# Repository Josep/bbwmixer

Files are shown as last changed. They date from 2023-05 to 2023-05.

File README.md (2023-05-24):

Audio Mixer and Volume MIDI controlled
======================================

This is a simple audio mixer with 4 analog stereo inputs and 1 output. The main volume 
and the volume of each input is controlled by MIDI messages.

The main volume is handled by the PGA2311 chip. The level of the 4 inputs are controlled by the
digital potentiometer MCP4251.

All the components are controlled by a Beaglebone White.

The midi interface is a classical one -not USB- with optocoupler 6N138.

The midi messages are handled in the PRU (Programmable Realtime Unit) of the Beaglebone.

No need to install capes or device tree overlays.

If you don't have a midi controller, the levels can be controlled from a web page too. In that case, an ethernet connection is needed.

Although the analog and digital power supply and grounds are separated in the design, they can be connected together with a jumper. So, the power from the BeagleBone will supply all the circuit. In my case, the results are good enough with the jumpers.

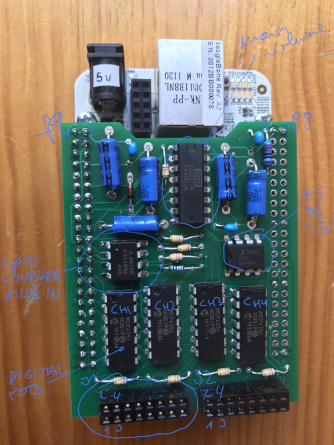
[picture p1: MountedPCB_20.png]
photo of mounted board here


J1 pinout
---------

    1  Left CH1
    2  Left CH1 GND  
    3  Right CH1
    4  Right CH1 GND
    5  Left CH2 GND
    6  Left CH2
    7  Right CH2 GND
    8  Right CH2
    9  Left CH3
    10 Left CH3 GND
    11 Right CH3
    12 Right CH3 GND
    13 Left CH4 GND
    14 Left CH4
    15 Right CH4 GND
    16 Right CH4

J2 pinout
---------

    1  Left out
    2  Left out GND
    3  Right out
    4  Right out GND
    5  Midi in (optocoupler)
    6  NC
    7  Midi in (R220)
    8  NC
    9  NC
    10 NC
    11 +3.3V
    12 NC
    13 +5V Digital
    14 +5V Analog
    15 Digital GND
    16 Analog GND

Beaglebone pins used
--------------------

    P8_1   GND
    P8_2   GND
    P9_1   GND
    P9_2   GND
    P9_4   VDD_3V3
    P9_8   +5V
    P9_11  gpio0_30  MUTE PGA2311
    P9_12  gpio1_28  ZCEN PGA2311
    P9_13  gpio0_31  CS CH3 MCP4251
    P9_14  gpio1_18  CS CH4 MCP4251
    P9_15  gpio1_16  SHDN CH1 MCP4251
    P9_16  gpio1_19  CS CH2 MCP4251
    P9_17  gpio0_5   CS PGA2311
    P9_21  gpio0_3   SPI DATA OUT PGA2311
    P9_22  gpio0_2   SPI CLK PGA2311
    P9_23  gpio1_17  SHDN CH2 MCP4251
    P9_25  gpio3_21  SHDN CH3 MCP4251
    P9_27  gpio3_19  SHDN CH4 MCP4251
    P9_28  gpio3_17  CS CH1 MCP4251
    P9_29  gpio3_15  SPI DATA OUT MCP4251
    P9_30  gpio3_16  SPI DATA IN MCP4251
    P9_31  gpio3_14  SPI CLK MCP4251
    P9_42  gpio7_7   MIDI IN

MIDI Messages Handled
---------------------

    B0 44 7F  Mute ON Main Volume
    B0 44 00  Mute OFF Main Volume
    BA 46 7F  Mute ON CH1
    BA 46 00  Mute OFF CH1
    BA 47 7F  Mute ON CH2
    BA 47 00  Mute OFF CH2
    BA 48 7F  Mute ON CH3
    BA 48 00  Mute OFF CH3
    BA 49 7F  Mute ON CH4
    BA 49 00  Mute OFF CH4
    B0 07 XX  Main Volume (XX: 00-7F)
    BA 07 XX  CH1 Level (XX: 00-7F)
    BA 4A XX  CH2 Level (XX: 00-7F)
    BA 4B XX  CH3 Level (XX: 00-7F)
    BA 4C XX  CH4 Level (XX: 00-7F)

Versions
--------
    
    python3.7, tornado server 6.2

    debian@bbwmixer:/opt/scripts/tools$ sudo ./version.sh
    git:/opt/scripts/:[1b1122751f7051bd8996f353756ba6ff30e71820]
    eeprom:[A335BONE00A50812BB000078]
    model:[TI_AM335x_BeagleBone]
    dogtag:[BeagleBoard.org Debian Buster Console Image 2020-04-06]
    bootloader:[microSD-(push-button)]:[/dev/mmcblk0]:[U-Boot SPL 2019.04-00002-g07d5700e21 (Mar 06 2020 - 11:24:55 -0600)]:[location: dd MBR]
    bootloader:[microSD-(push-button)]:[/dev/mmcblk0]:[U-Boot 2019.04-00002-g07d5700e21]:[location: dd MBR]
    UBOOT: Booted Device-Tree:[am335x-bone-uboot-univ.dts]
    UBOOT: Loaded Overlay:[AM335X-PRU-RPROC-4-19-TI-00A0]
    kernel:[4.19.94-ti-r73]
    nodejs:[v10.24.0]
    /boot/uEnv.txt Settings:
    uboot_overlay_options:[enable_uboot_overlays=1]
    uboot_overlay_options:[disable_uboot_overlay_emmc=1]
    uboot_overlay_options:[disable_uboot_overlay_video=1]
    uboot_overlay_options:[disable_uboot_overlay_audio=1]
    uboot_overlay_options:[disable_uboot_overlay_wireless=1]
    uboot_overlay_options:[disable_uboot_overlay_adc=1]
    uboot_overlay_options:[uboot_overlay_pru=/lib/firmware/AM335X-PRU-RPROC-4-19-TI-00A0.dtbo]
    uboot_overlay_options:[enable_uboot_cape_universal=1]

Known issues
------------

- Hardware: The channels 3 and 4 SPI return information from the MCP4251 chip are not connected. A wire can be soldered if the SPI return information is needed. This is optional because the returned information is not used currently by the software.
- Software: The state of the mute buttons is not updated when the mixer is started. 
- Software: The response to the volume changes may be a little slow. This is due -I suppose- to the fact that the SPI protocol is implemented with GPIOs instead of the true SPI hardware included in the beaglebone. I tried but could not make it work.

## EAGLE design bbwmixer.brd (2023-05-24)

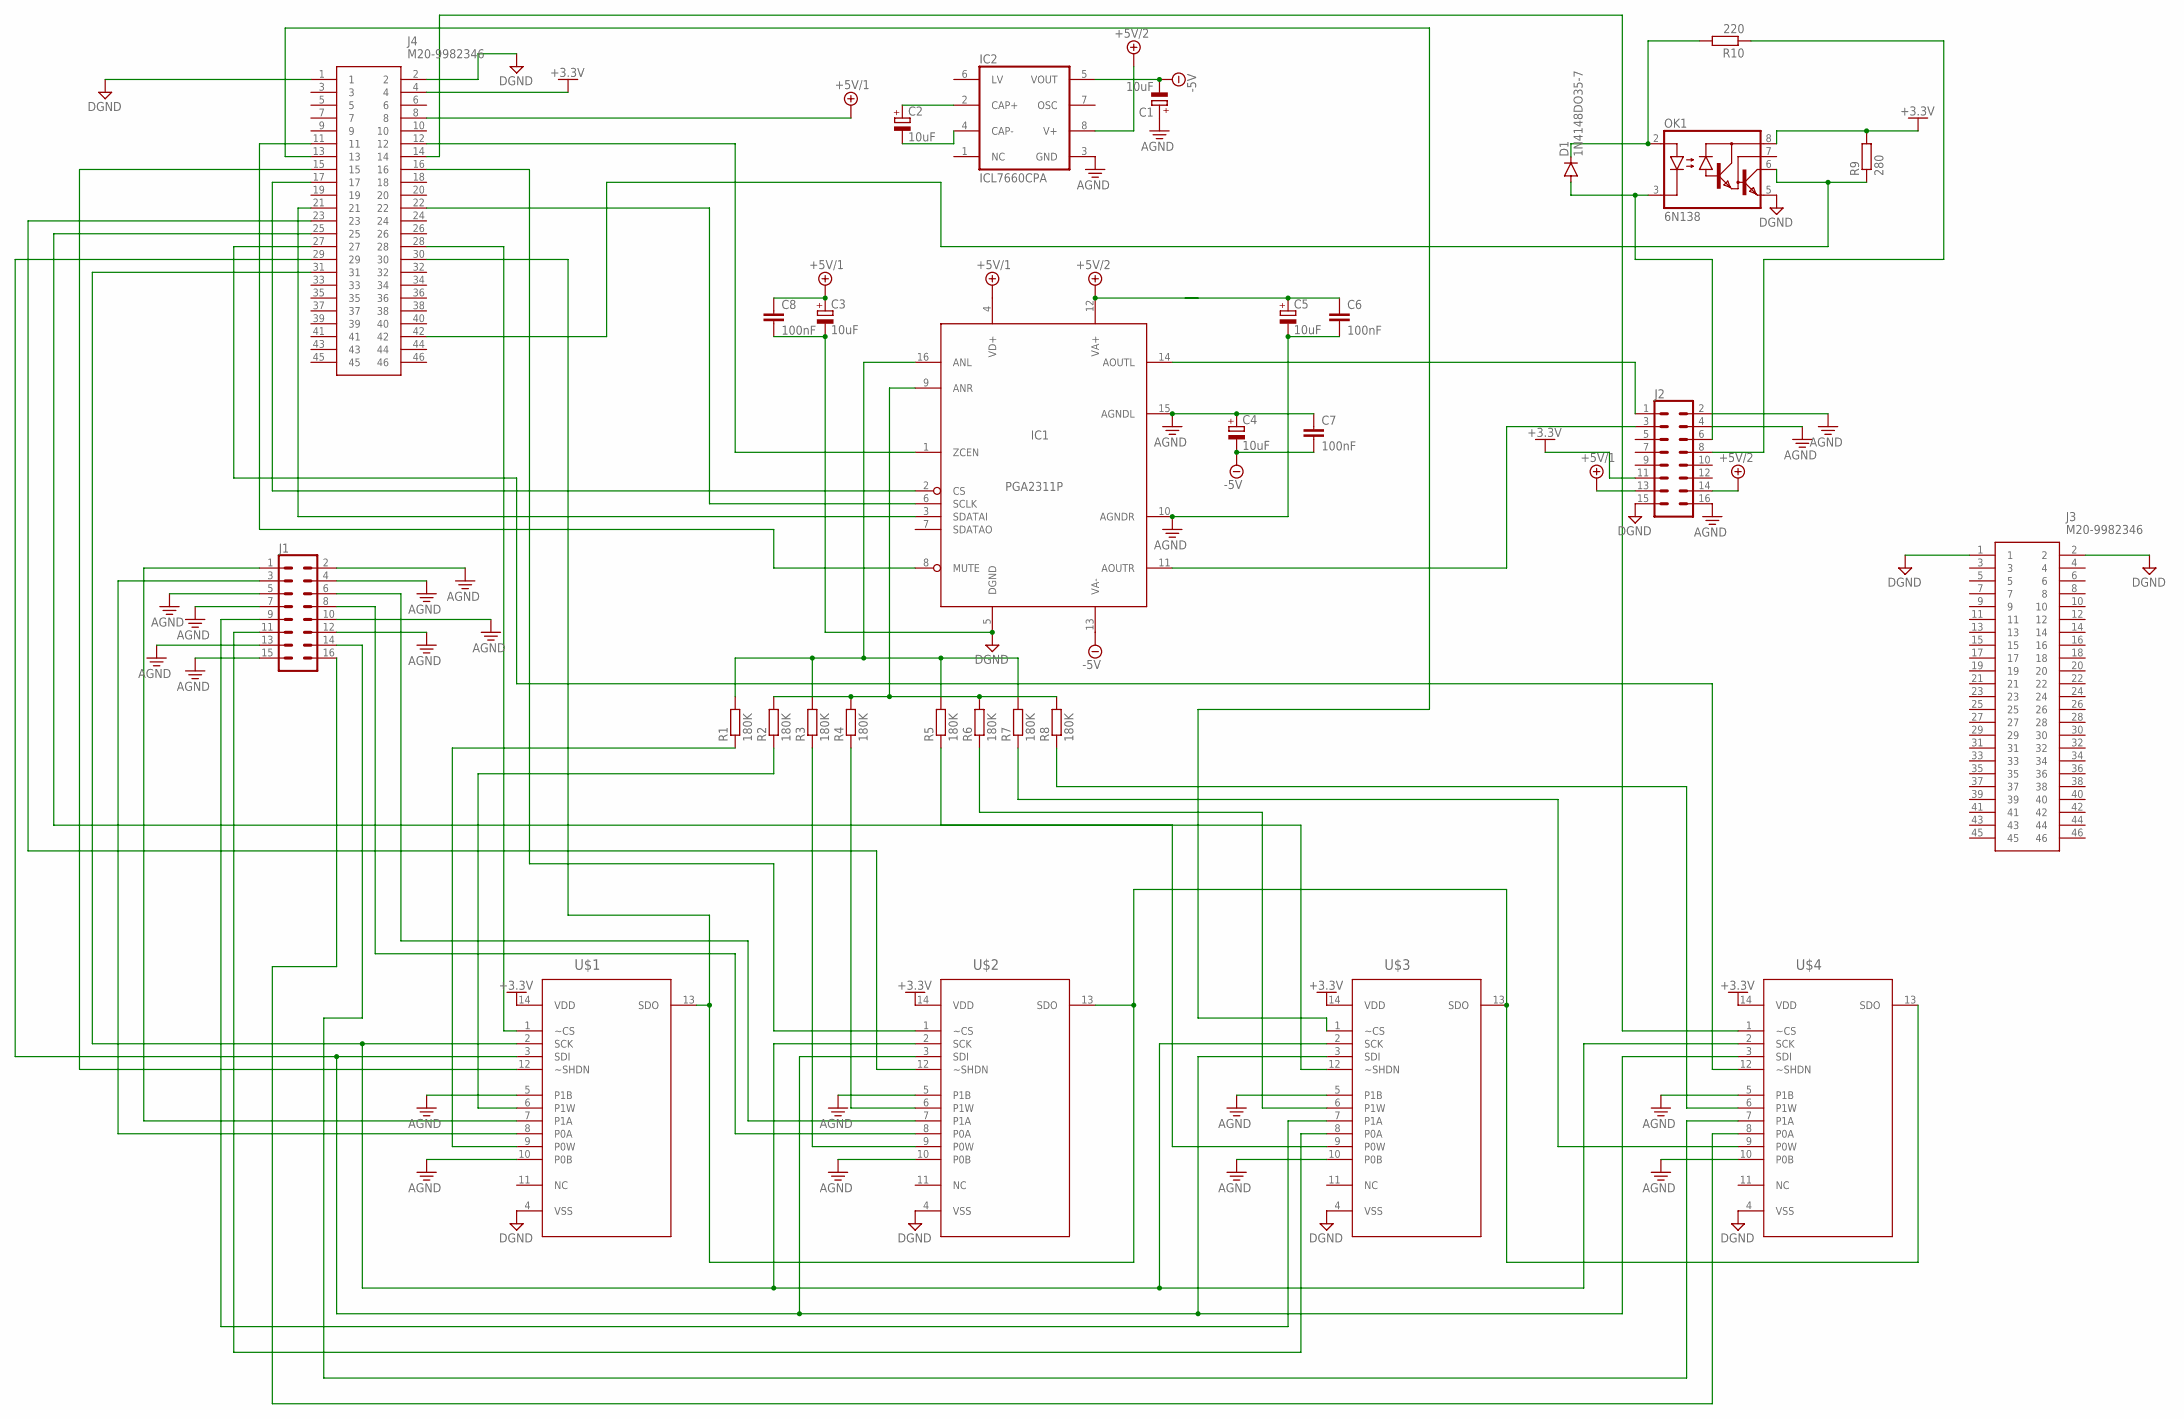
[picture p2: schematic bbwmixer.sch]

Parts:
C1, C2, C3, C4, C5: 10uF; E15-5
C6, C7, C8: 100nF; C050-025X075
D1: 1N4148DO35-7; DO35-7
IC1: PGA2311P; DIL16
IC2: ICL7660CPA; DIL08
J1, J2: CONN_08X2; 2X8
J3, J4: M20-9982346
OK1: 6N138; DIL08
R1, R2, R3, R4, R5, R6, R7, R8: 180K; 0207/10
R9: 280; 0207/10
R10: 220; 0207/10
U$1, U$2, U$3, U$4: MCP4251-103E/P; DIP254P762X533-14

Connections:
+3.3V: J2.11, J4.4, OK1.8 (VCC), R9.2, U$1.14 (VDD), U$2.14 (VDD), U$3.14 (VDD), U$4.14 (VDD)
+5V/1: C3.+, C8.1, IC1.4 (VD+), J2.13, J4.8
+5V/2: IC1.12 (VA+), IC2.8 (V+), J2.14
-5V: C1.-, C4.-, C7.2, IC1.13 (VA-), IC2.5 (VOUT)
AGND: C1.+, C4.+, C5.-, C6.2, C7.1, IC1.10 (AGNDR), IC1.15 (AGNDL), IC2.3 (GND), J1.2, J1.4, J1.5, J1.7, J1.10, J1.12, J1.13, J1.15, J2.2, J2.4, J2.16, U$1.5 (P1B), U$1.10 (P0B), U$2.5 (P1B), U$2.10 (P0B), U$3.5 (P1B), U$3.10 (P0B), U$4.5 (P1B), U$4.10 (P0B)
DGND: C3.-, C8.2, IC1.5 (DGND), J2.15, J3.1, J3.2, J4.1, J4.2, OK1.5 (GND), U$1.4 (VSS), U$2.4 (VSS), U$3.4 (VSS), U$4.4 (VSS)
unnamed: C2.+, IC2.2 (CAP+)
unnamed: C2.-, IC2.4 (CAP-)
unnamed: C5.+, C6.1
unnamed: R1.1, U$1.9 (P0W)
unnamed: R2.1, U$1.6 (P1W)
unnamed: R3.1, U$2.9 (P0W)
unnamed: R4.1, U$2.6 (P1W)
unnamed: R5.1, U$3.9 (P0W)
unnamed: R6.1, U$3.6 (P1W)
unnamed: R7.1, U$4.9 (P0W)
unnamed: R8.1, U$4.6 (P1W)
unnamed: IC1.16 (ANL), R1.2, R3.2, R5.2, R7.2
unnamed: IC1.9 (ANR), R2.2, R4.2, R6.2, R8.2
unnamed: J4.31, U$1.2 (SCK), U$2.2 (SCK), U$3.2 (SCK), U$4.2 (SCK)
unnamed: J1.3, U$1.8 (P0A)
unnamed: J4.29, U$1.3 (SDI), U$2.3 (SDI), U$3.3 (SDI), U$4.3 (SDI)
unnamed: J1.1, U$1.7 (P1A)
unnamed: J1.8, U$2.8 (P0A)
unnamed: J1.6, U$2.7 (P1A)
unnamed: J1.9, U$3.7 (P1A)
unnamed: J1.11, U$3.8 (P0A)
unnamed: J1.14, U$4.7 (P1A)
unnamed: J1.16, U$4.8 (P0A)
unnamed: IC1.14 (AOUTL), J2.1
unnamed: IC1.11 (AOUTR), J2.3
unnamed: IC1.2 (CS), J4.17
unnamed: IC1.3 (SDATAI), J4.21
unnamed: IC1.6 (SCLK), J4.22
unnamed: IC1.8 (MUTE), J4.11
unnamed: IC1.1 (ZCEN), J4.12
unnamed: J4.15, U$1.12 (~SHDN)
unnamed: J4.23, U$2.12 (~SHDN)
unnamed: J4.25, U$3.12 (~SHDN)
unnamed: J4.27, U$4.12 (~SHDN)
unnamed: J4.28, U$1.1 (~CS)
unnamed: J4.16, U$2.1 (~CS)
unnamed: J4.13, U$3.1 (~CS)
unnamed: J4.14, U$4.1 (~CS)
unnamed: J4.42, OK1.6 (VO), R9.1
unnamed: D1.A, J2.6, OK1.3 (C)
unnamed: D1.C, OK1.2 (A), R10.2
unnamed: J2.8, R10.1

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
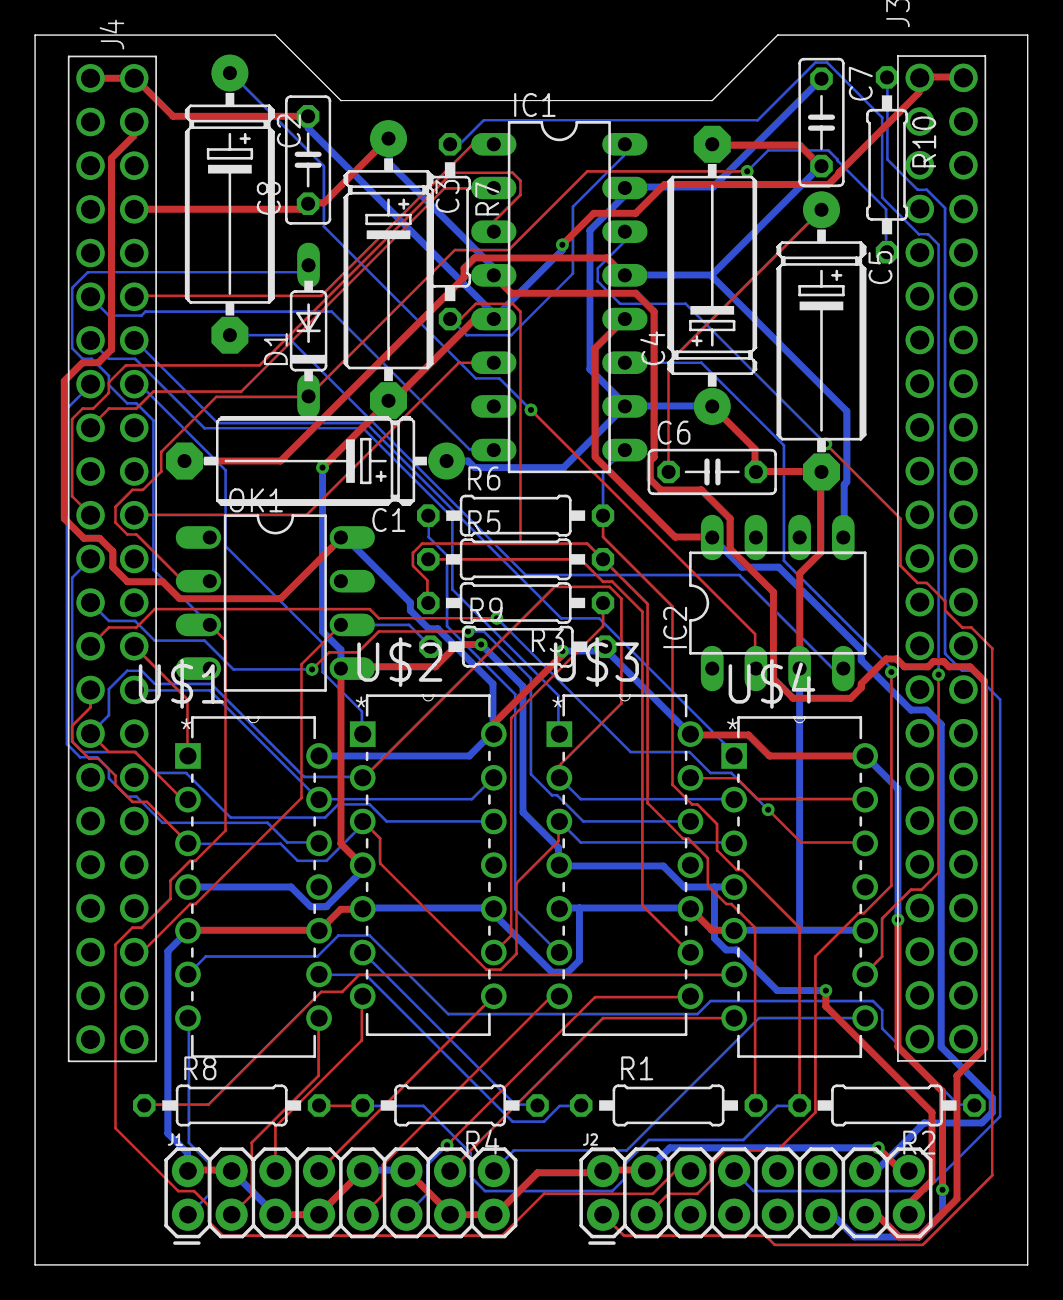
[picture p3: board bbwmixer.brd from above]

Board: 2 copper layers, 57.7 x 71.5 mm, 30 parts (0 on the bottom side), 50 nets.

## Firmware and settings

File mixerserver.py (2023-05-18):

import sys
import os
import pickle
import asyncio
import tornado.web
import programports
import getmidi

class Status():
    def __init__(self):
        #read pickle file if exists
        self.picklefile = 'status.pickle'
        if os.path.isfile(self.picklefile):
            with open(self.picklefile,'rb') as f:
                self.__dict__ = pickle.load(f)
        else:
            self.m = 0xb8b8
            self.c1l = 0x007f
            self.c2l = 0x007f
            self.c3l = 0x007f
            self.c4l = 0x007f
            self.c1r = 0x107f
            self.c2r = 0x107f
            self.c3r = 0x107f
            self.c4r = 0x107f
            self.mute_m = 0
            self.mute_c1 = 0
            self.mute_c2 = 0
            self.mute_c3 = 0
            self.mute_c4 = 0
            self.zc_m = 0
            pickle.dump(self.__dict__,open(self.picklefile,'wb'))

    def save(self):
        pickle.dump(self.__dict__,open(self.picklefile,'wb'))
            
class SliderHandler(tornado.web.RequestHandler):

    def printarg(self, arg):
        val = self.get_argument(arg,None)
        if val != None:
            arg2 = arg[:-1]+'r'
            val2 = self.get_argument(arg2,None)
            print(arg, hex(int(val)), arg2, hex(int(val2)))
            if arg == 'ml':
                val = pp.tlog(int(val))
                val2 = pp.tlog(int(val2))
                pp.send2311((val<<8)+val2)
                st.ml = (val<<8)+val2
            if arg == 'c1l':
                pp.send(int(val), cs=0)
                st.c1l = int(val)
                pp.send(0x1000+int(val2), cs=0)
                st.c1r = 0x1000+int(val2)
            if arg == 'c2l':
                pp.send(int(val), cs=1)
                st.c2l = int(val)
                pp.send(0x1000+int(val2), cs=1)
                st.c2r = 0x1000+int(val2)
            if arg == 'c3l':
                pp.send(int(val), cs=2)
                st.c3l = int(val)
                pp.send(0x1000+int(val2), cs=2)
                st.c3r = 0x1000+int(val2)
            if arg == 'c4l':
                pp.send(int(val), cs=3)
                st.c4l = int(val)
                pp.send(0x1000+int(val2), cs=3)
                st.c4r = 0x1000+int(val2)
            st.save()

    def get(self):
        args = ['ml','c1l','c2l','c3l','c4l']
        for i in args:
            self.printarg(i)

class CheckBoxHandler(tornado.web.RequestHandler):
    def printarg(self, arg):
        val = self.get_argument(arg,None)
        if val != None:
            print(arg, val)
            pp.setpin(*self.dicc[arg],val=='true')

    def get(self):
        self.dicc = {'mute_m':(0,30),'mute_c1':(1,16),'mute_c2':(1,17),'mute_c3':(3,21),'mute_c4':(3,19),'zc_m':(1,28)}
        for i in self.dicc.keys():
            self.printarg(i)

def make_app():
    return tornado.web.Application([
        (r'/sliders', SliderHandler),
        (r'/checkboxes', CheckBoxHandler),
        (r"/(.*)", tornado.web.StaticFileHandler, {"path":"."}),
    ])

async def main():
    app = make_app()
    app.listen(80)
    shutdown_event = asyncio.Event()
    await shutdown_event.wait()

if __name__ == '__main__':
    #requirements
    if sys.version_info[0] != 3:
        sys.exit("python3 required")
    if os.geteuid() != 0:
        sys.exit("You need to have root privileges")
    st = Status()
    print('Program ports...')
    pp = programports.ProgPorts()
    pp.send2311(st.m)
    pp.send(st.c1l,cs=0)
    pp.send(st.c1r,cs=0)
    pp.send(st.c2l,cs=1)
    pp.send(st.c2r,cs=1)
    pp.send(st.c3l,cs=2)
    pp.send(st.c3r,cs=2)
    pp.send(st.c4l,cs=3)
    pp.send(st.c4r,cs=3)
    print("Starting midi reader...")
    gm = getmidi.GetMidi()
    gm.begin(pp,st)
    print("Starting web server...")
    asyncio.run(main())

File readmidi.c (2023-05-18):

#include "readmidi.h"

#define GPIO0_REGS 0x44e07000
#define GPIO0_DATAIN GPIO0_REGS | 0x138
#define GPIO0_OE GPIO0_REGS | 0x134
#define BITLENGTH 6400
#define BITLENGTHHALF 3200
#define DRAM2 0x10000
#define INCRIBUF {if (ibuf >= bufend) ibuf = bufstart;}

#ifdef PRUN0
#define BUFSTART 0x1004
#define BUFEND 0x1fd8
#define CFGGPIOPIN 0x44e10808
#define CLEARPMAO 0
#define POSIESCR 8
#define POSILECT 0x0c
#define CFGCTRLADDR 0x22000
#define MIDIINPIN 2
#endif
#ifdef PRUN1
#define BUFSTART 0x20
#define BUFEND 0xff4
#define CFGGPIOPIN 0x44e10964
#define CLEARPMAO 1
#define POSIESCR 0
#define POSILECT 4
#define CFGCTRLADDR 0x24000
#define MIDIINPIN 7
#endif

uint32_t inpin;
volatile uint32_t *cfgaddr;
volatile uint32_t *inaddr;
volatile uint32_t *debug;
volatile uint32_t *errstart, *errstop;
volatile uint8_t *shram = (uint8_t *) DRAM2;
volatile uint32_t *cfgctrl, *counter;
volatile uint32_t val32;
uint32_t bufstart = BUFSTART;
uint32_t bufend = BUFEND;
uint32_t ibuf;
uint32_t *iescr;
uint32_t *ilect;
uint8_t runstatus = 0;
uint8_t sysexownstatus = 0;

void init_interrupt() {
#ifdef PRUN1
    uint32_t *addr = (uint32_t *) (DRAM2+0xff8);
    *addr = 0xff;
#endif
}

void activate_interrupt(uint8_t command) {
#ifdef PRUN1
    uint32_t *addr = (uint32_t *) (DRAM2+0xff8);
    *addr = command;
#endif
}

void clearcycles() {
    /* PRU_CTRL.CONTROL_bit.COUNTER_ENABLE = 0 */
    val32 = ~(1<<3);
    *cfgctrl &= val32;
    /* PRU_CTRL.CYCLE = 0 */
    *counter = 0;
    /* PRU_CTRL.CONTROL_bit.COUNTER_ENABLE */
    val32 = (1<<3);
    *cfgctrl |= val32;
}

uint8_t readbyte() {
    uint32_t v32, vin;
    uint8_t byte = 0;
    /* step 1: at least 2 readings with 1 */
    while(1) {
        v32 = *inaddr;
        vin = v32 & inpin;
        if  (vin==inpin) {
            v32 = *inaddr;
            vin = v32 & inpin;
            if  (vin==inpin) {
                break;
            }
        }
    }
    /* step 2: search start bit */
    while(1) {
        v32 = *inaddr;
        vin = v32 & inpin;
            clearcycles();
        if  (vin!=inpin) {
            v32 = *inaddr;
            vin = v32 & inpin;
            if  (vin!=inpin) {
                break;
            }
        }
    }
    while ((*counter) < BITLENGTHHALF){;}
    if (((((*inaddr)&inpin)==inpin)?1:0) == 1) {
        *errstart = (*errstart) + 1;
    }
    while ((*counter) < BITLENGTH){;}
    /* step 3: read bits in the center */
    __delay_cycles(BITLENGTHHALF);
    byte += ((((*inaddr)&inpin)==inpin)?1:0);
    __delay_cycles(BITLENGTH);
    byte += ((((*inaddr)&inpin)==inpin)?1:0) << 1;
    __delay_cycles(BITLENGTH);
    byte += ((((*inaddr)&inpin)==inpin)?1:0) << 2;
    __delay_cycles(BITLENGTH);
    byte += ((((*inaddr)&inpin)==inpin)?1:0) << 3;
    __delay_cycles(BITLENGTH);
    byte += ((((*inaddr)&inpin)==inpin)?1:0) << 4;
    __delay_cycles(BITLENGTH);
    byte += ((((*inaddr)&inpin)==inpin)?1:0) << 5;
    __delay_cycles(BITLENGTH);
    byte += ((((*inaddr)&inpin)==inpin)?1:0) << 6;
    __delay_cycles(BITLENGTH);
    byte += ((((*inaddr)&inpin)==inpin)?1:0) << 7;
    __delay_cycles(BITLENGTH);
    /* step 4: stop bit */
    if (((((*inaddr)&inpin)==inpin)?1:0) != 1) {
        *errstop = (*errstop) + 1;
    }
    return byte;
}

void readbyteinit(uint32_t cfgctrladdr) {
    volatile uint32_t *datain;
    datain = (uint32_t *)(GPIO0_DATAIN);
    /* step 1: wait for 15 bits without activity */ 
    clearcycles();
    cfgaddr = (uint32_t *) cfgctrladdr;
    while(1) {
        if (((*datain)&inpin)==inpin) {
            __delay_cycles(0);
            if ((*cfgaddr) > (15*BITLENGTH)) {
                break;
            }
        }
        else {
            clearcycles();
        }
    }
}

void initialize() {
    inpin = 1 << MIDIINPIN;
    ibuf = bufstart;
    /* Clear SYSCFG[STANDBY_INIT] to enable OCP master port */
    cfgaddr = (uint32_t *)0x26004;
    val32 = ~(1<<4);
    *cfgaddr &= val32;
    /* Clear PMAO PRU */
    cfgaddr = (uint32_t *)0x26028;
    val32 = ~(1<<CLEARPMAO);
    *cfgaddr &= val32;
    /* MIDIIN PIN */
    cfgaddr = (uint32_t *) CFGGPIOPIN;
    *cfgaddr = 0x000027;
    cfgaddr = (uint32_t *) (GPIO0_OE);
    *cfgaddr |= inpin;
    /* indice escritura de midiin */
    iescr = (uint32_t *) &shram[POSIESCR]; 
    *iescr = bufstart;
    /* indice lectura de midiin */
    ilect = (uint32_t *) &shram[POSILECT]; 
    *ilect = bufstart;
    /* clear buffer */
    bzero((void *)&shram[bufstart], bufend-bufstart);
    /* inaddr */
    inaddr = (uint32_t *) (GPIO0_DATAIN);
    /* errors startbit */
    errstart = (uint32_t *) &shram[0x2fcc];
    *errstart = 0;
    /* errors stopbit */
    errstop = (uint32_t *) &shram[0x2fd0];
    *errstop = 0;
    /* cycle counter */
    cfgctrl = (uint32_t *) CFGCTRLADDR;
    counter = (uint32_t *) (CFGCTRLADDR + 0x0c);
    /* debug */
    debug = (uint32_t *) &shram[0x1c];
    /* other inits */
    readbyteinit(CFGCTRLADDR + 0x0c);
    init_interrupt();
}
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

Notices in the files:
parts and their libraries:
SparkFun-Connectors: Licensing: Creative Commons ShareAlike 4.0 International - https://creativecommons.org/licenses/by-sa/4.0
